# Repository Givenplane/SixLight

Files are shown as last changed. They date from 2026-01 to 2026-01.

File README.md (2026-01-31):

# SixLight – Modular Hexagonal LED System with Adjustable Joints

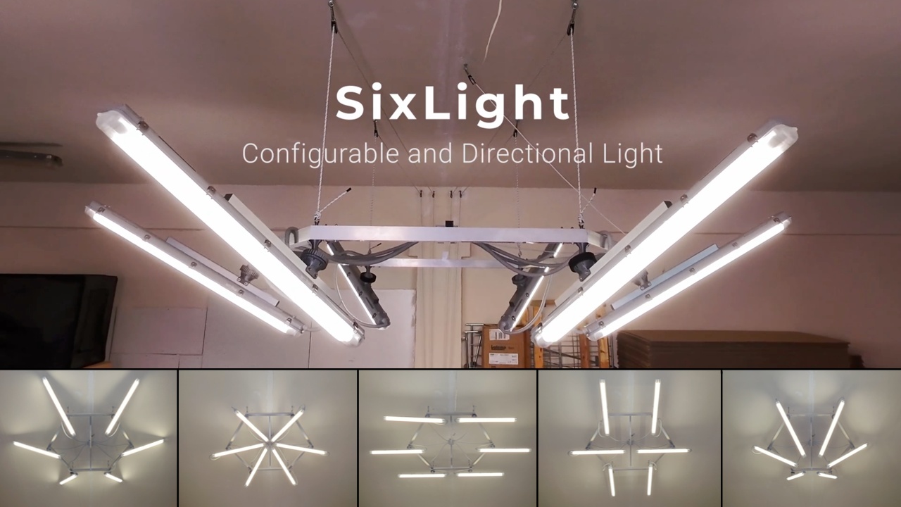
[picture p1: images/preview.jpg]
SixLight Cover


**SixLight** is a modular lighting system designed for creators, makers, and content producers. It combines industrial reliability with DIY flexibility, allowing you to build a durable, adjustable LED light for your studio, workshop, or filming setup.

🎥 **Watch the full video on YouTube:**  
[▶️ SixLight Video](https://www.youtube.com/watch?v=seigdt7EmHs)

---

## 🧱 Structure & Design

SixLight is built around a hexagonal frame made of 50x50 mm aluminum tubes, each 2 mm thick. The industrial LED housings are attached to the frame using custom-designed spherical joints, which allow for a wide range of positioning. Aluminum tubes were chosen to keep the cost low, but using carbon fiber tubes would significantly reduce the weight and improve maneuverability.

Each joint can be tightened to lock the light in a desired direction, offering a semi-rigid structure that remains flexible during setup but stable during use.

---

## 🔩 What's Inside

- 3D-printable STL files for the spherical joints and mounting elements
- STEP files for modification
- [ A short guide](docs/assembly_guide.md) and images of the final assembly

---

## 🚀 Potential Improvements

Here are some possible upgrades and features that could enhance future versions of SixLight:

- **Remote control of individual lamps** for power or on/off switching
- **Brightness adjustment** through dimmable drivers or smart controllers
- **Replacement of the spherical joints** with motorized articulation systems to remotely adjust lamp orientation
- **Motorized ceiling rigging** to raise or lower the four suspension points for positioning and maintenance

---

## 📜 License

This project is licensed under **Creative Commons BY-NC-SA 4.0**.  
You may use, modify, and share this project for **non-commercial** purposes only.

🔒 **Commercial use is not allowed without a separate agreement.**  
If you're a company or manufacturer interested in using or producing this system, please contact us.

---

## ⚠️ Disclaimer

This project is provided **"as is"** without any warranty of any kind, either express or implied.

By using, building, or modifying this project, you agree that:

- You do so **at your own risk**.
- The author(s) are **not responsible for any damage**, injury, or loss that may result from the use or misuse of this design.
- This project involves **electrical components** and **structural parts** that, if improperly built or installed, may cause **fire, electric shock, injury, or property damage**.
- It is **your responsibility** to verify the safety, compliance, and suitability of the design for your specific application.

Always follow local safety regulations and consult a qualified professional when working with electricity or mechanical structures.

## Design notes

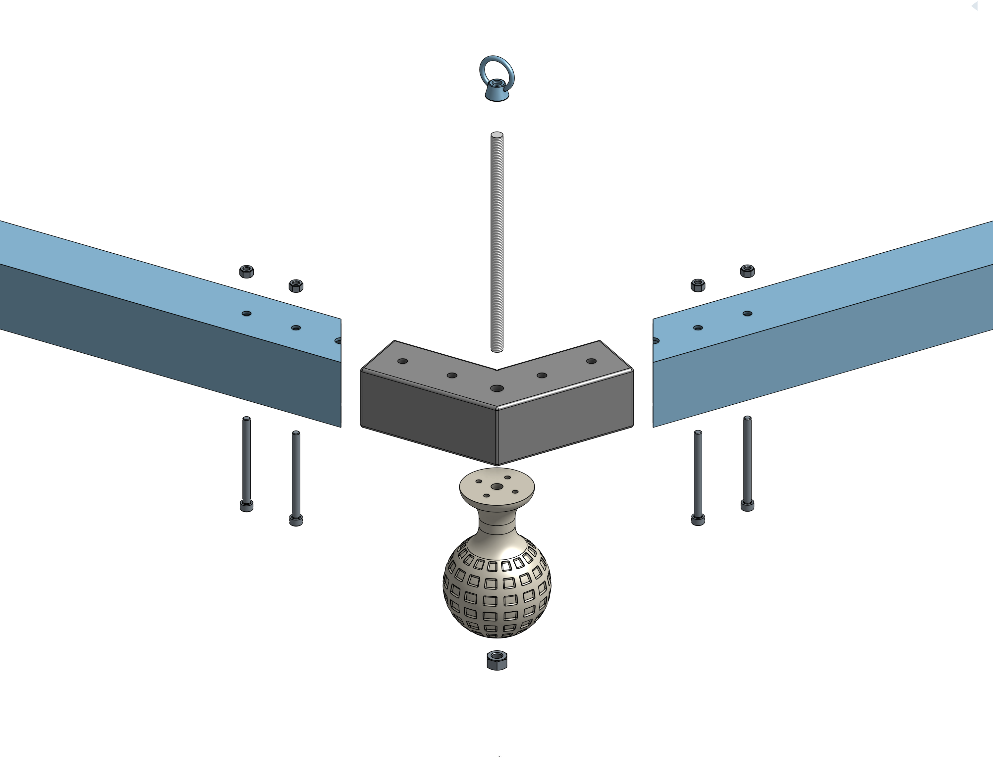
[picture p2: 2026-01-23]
images/hexagon-corner.png

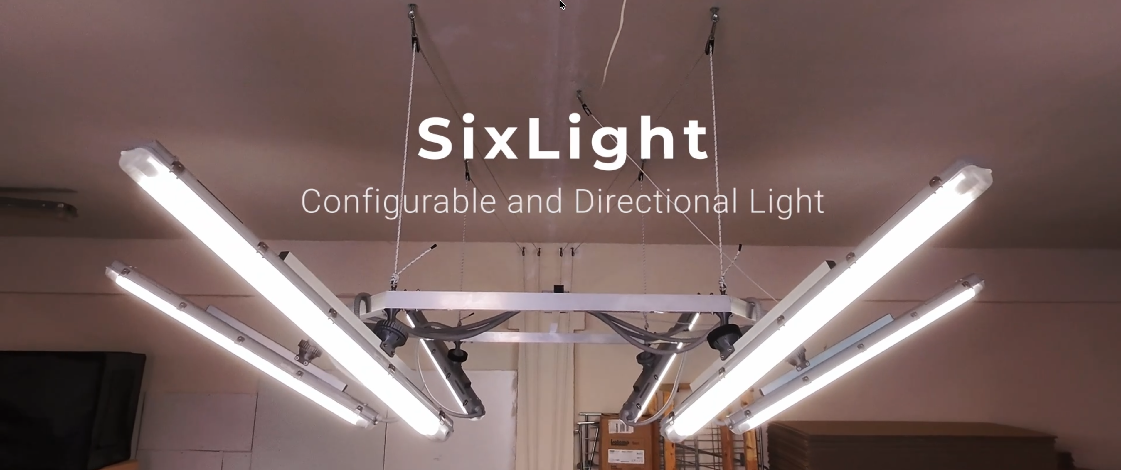
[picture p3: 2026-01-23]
images/cover.png

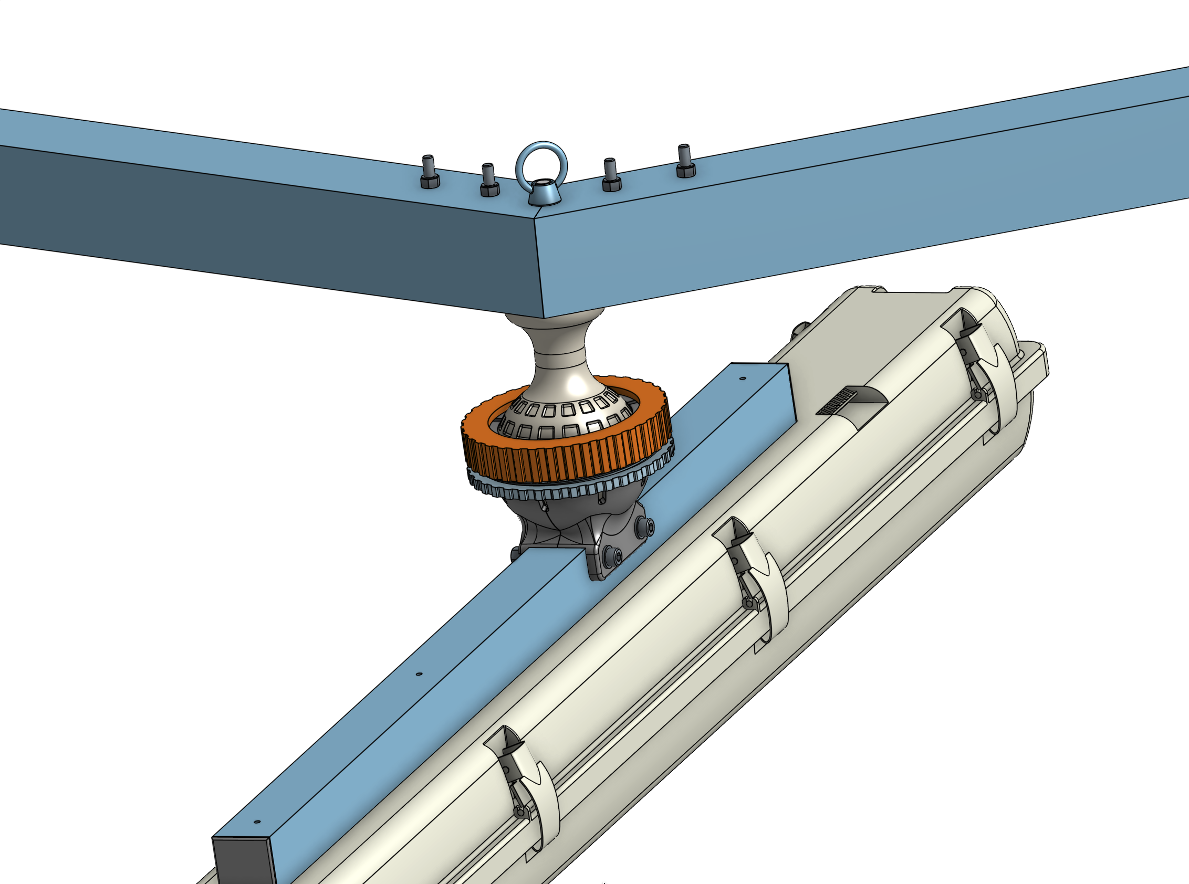
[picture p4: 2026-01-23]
images/ball-joint-tightened.png

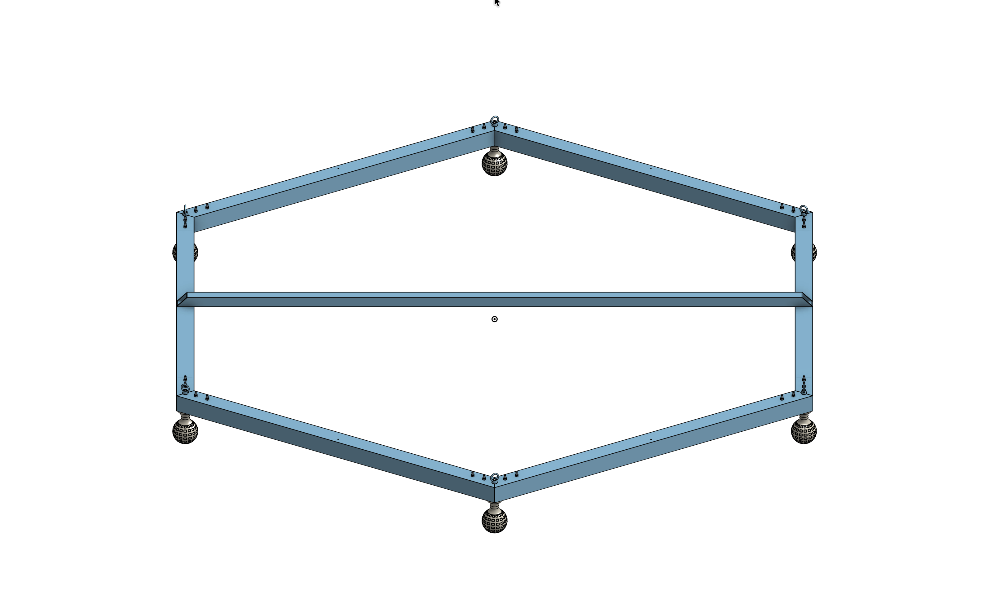
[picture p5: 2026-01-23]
images/hexagon-frame.png

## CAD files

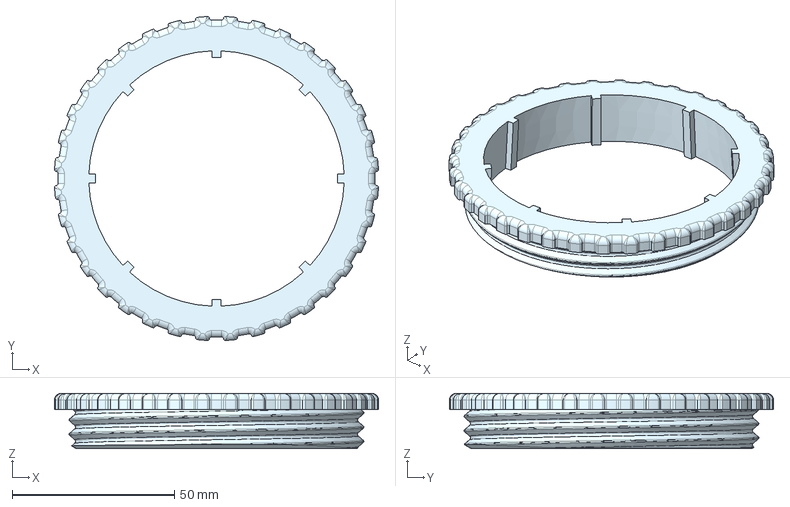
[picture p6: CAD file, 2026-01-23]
3d_models/015-Ball-joint_Male-threaded-ring.step
99.8 x 99.8 x 17.0 mm

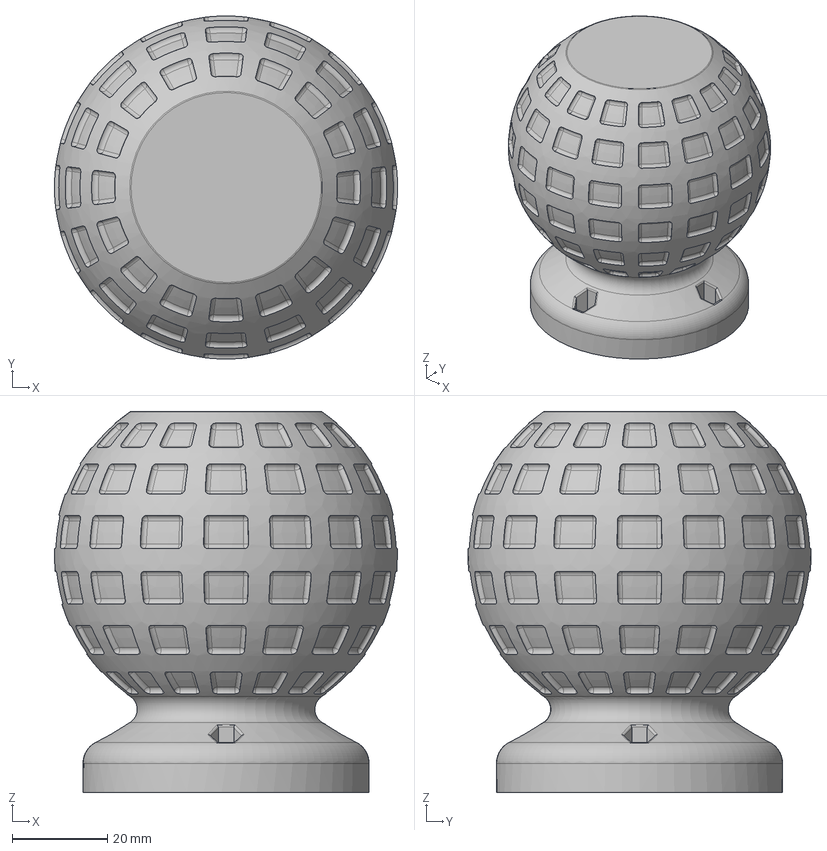
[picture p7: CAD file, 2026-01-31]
3d_models/flat_base_ball_joint/Ball-joint - Sphere.step
71.9 x 71.9 x 79.9 mm

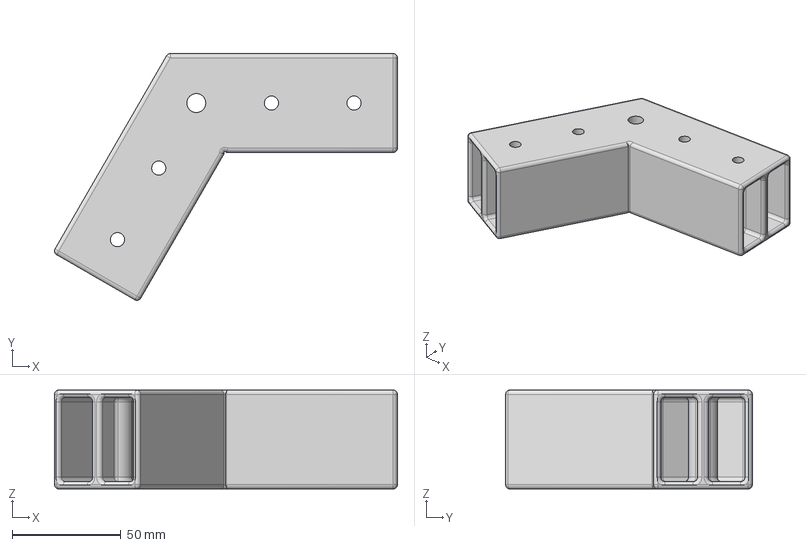
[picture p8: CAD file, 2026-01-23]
3d_models/002-Exagon-structure_Frame-joint.step
157.8 x 113.6 x 45.5 mm

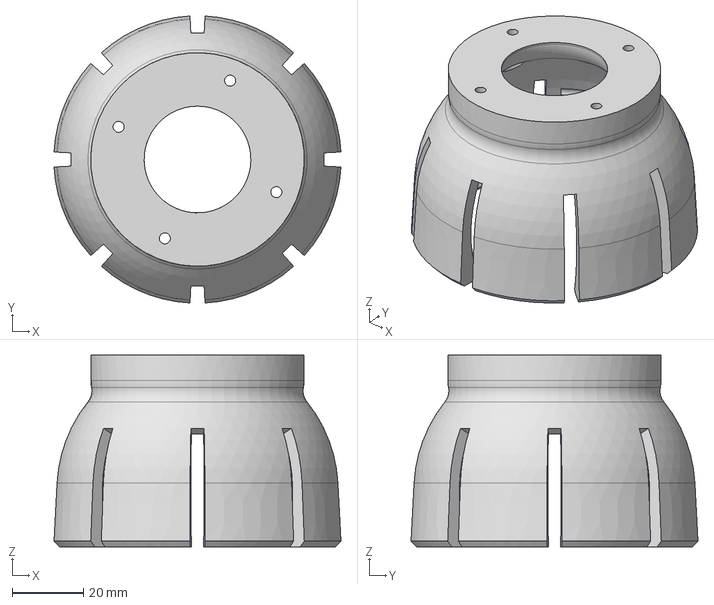
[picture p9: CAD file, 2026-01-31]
3d_models/flat_base_ball_joint/Ball-joint - Fixing.step
80.7 x 80.7 x 53.9 mm

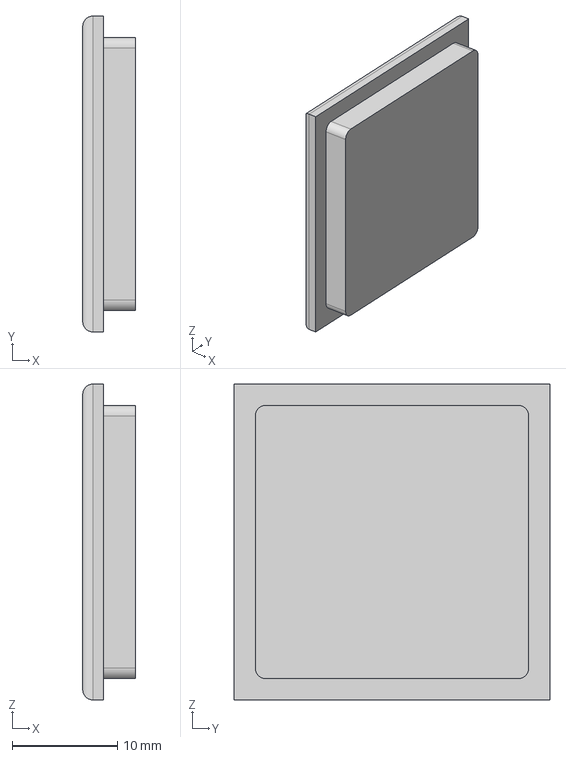
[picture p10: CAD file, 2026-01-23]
3d_models/010-LED-housing_30x30-cap.step
5.00 x 30.0 x 30.0 mm

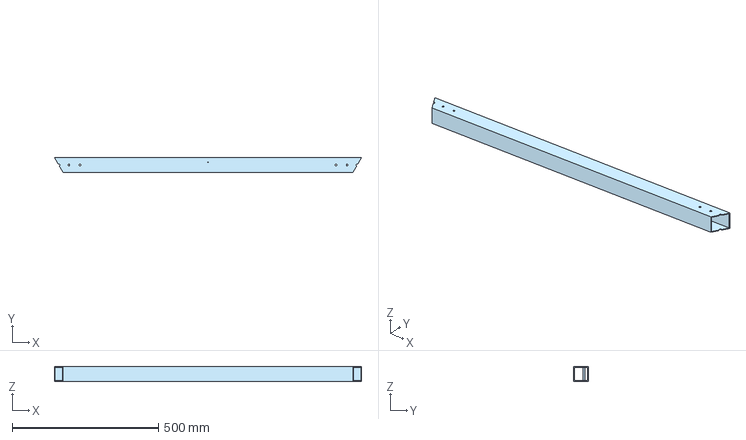
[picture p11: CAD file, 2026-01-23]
3d_models/001-Exagon-structure_Side.step
1050.0 x 50.0 x 50.0 mm

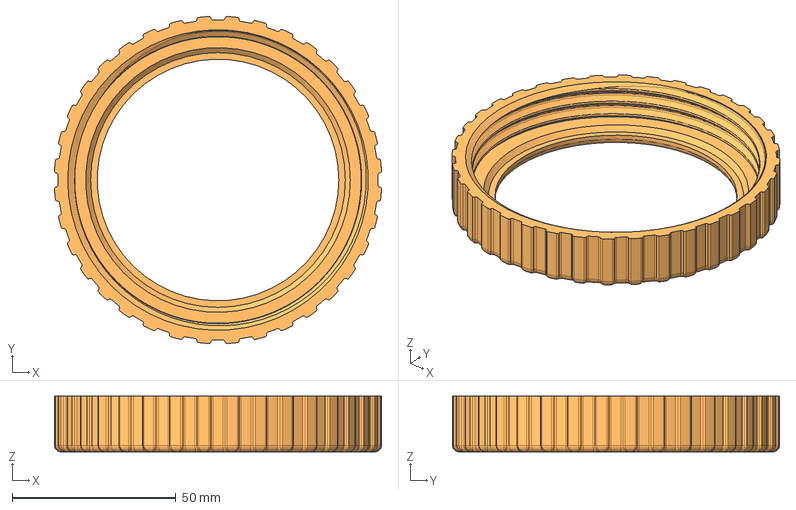
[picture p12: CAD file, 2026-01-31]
3d_models/flat_base_ball_joint/Ball-joint - Female-threaded-ring.step
99.8 x 99.8 x 17.0 mm

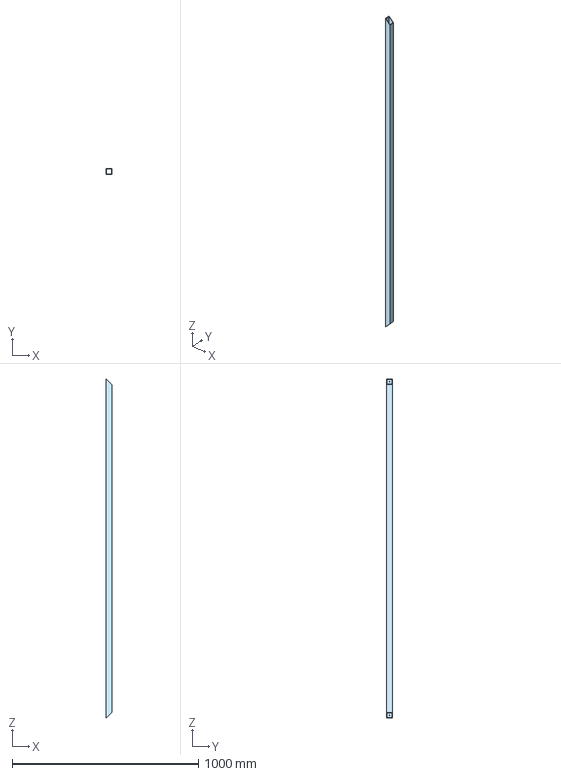
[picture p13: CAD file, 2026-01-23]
3d_models/019-Exagon-structure_Support-bar.step
30.0 x 30.0 x 1818.0 mm

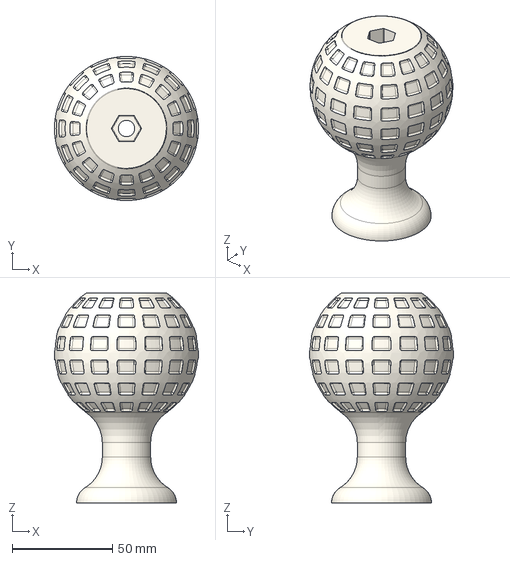
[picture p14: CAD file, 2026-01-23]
3d_models/003-Ball-joint _Sphere.step
72.0 x 72.0 x 104.9 mm

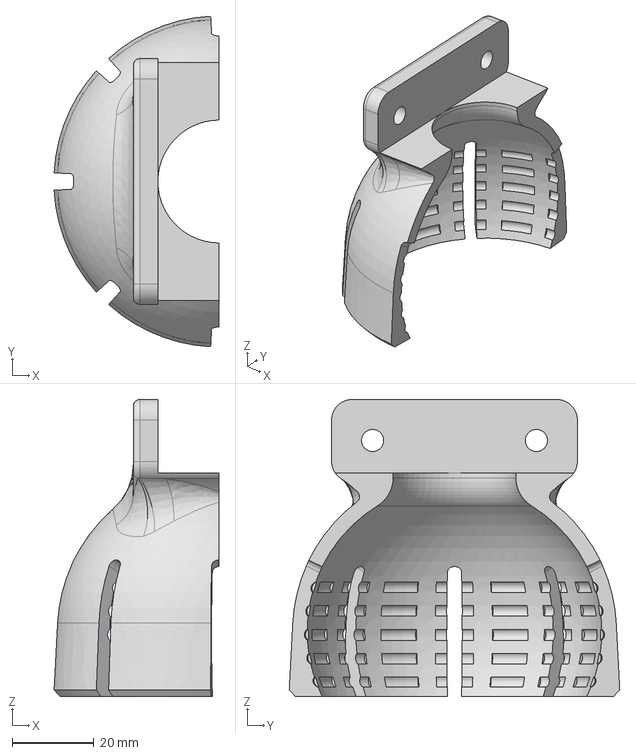
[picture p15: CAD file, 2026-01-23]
3d_models/013-Ball-joint_Fixing.step
40.2 x 80.7 x 72.5 mm

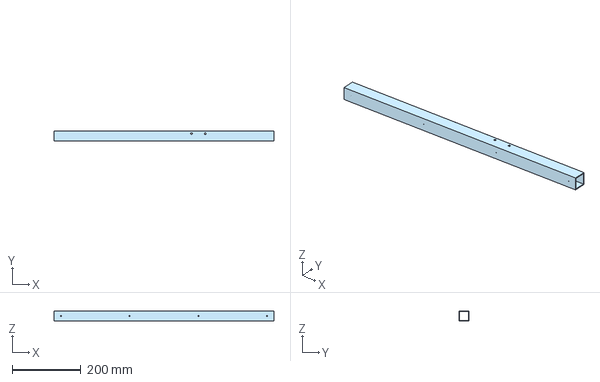
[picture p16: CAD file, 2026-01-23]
3d_models/012-LED-housing_Support.step
640.0 x 30.0 x 30.0 mm

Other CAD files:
3d_models/flat_base_ball_joint/Ball-joint - Male-threaded-ring.step
3d_models/014-Ball-joint_Female-threaded-ring.step
3d_models/flat_base_ball_joint/stl/Ball-joint - Fixing.stl
3d_models/stl/002-Exagon-structure_Frame-joint.stl
3d_models/stl/010-LED-housing_30x30-cap.stl
3d_models/stl/013-Ball-joint_Fixing.stl

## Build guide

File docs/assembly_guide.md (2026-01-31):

# SixLight – Assembly Guide

> This guide covers the assembly of the **SixLight** lamp structure only.  
> This is a short illustrated guide to the **SixLight** lamp structure only.
> Electrical wiring and the ceiling pulley system are not described here but referenced in the final images.

---

## 📦 Part List

| Part number | Quantity | Description |
|---|---|---|
| 001 | 6 | 50x50x1000mm Alluminium profile 2mm thickness |
| 002 | 6 | 3d printed frame joint |
| 003 | 6 | 3d printed sphere |
| 004 | 6 | M8 x 165mm threaded bar |
| 005 | 24 | Hex socket head cap screw M5x0.80 x 65 Stainless Steel |
| 006 | 6 | Self-locking hex nut M8 Stainless Steel |
| 007 | 24 | Hex nut M5 Stainless Steel |
| 008 | 6 | M8 eyebolt |
| *009* | *6* | *Assembly of LED fixtures (cad reference)* |
| 010 | 12 | 3d printed Caps |
| 011 | 6 | Industrial 120cm LED batten housing |
| 012 | 6 | 30x30x640mm Alluminium profile 2mm thickness |
| 013 | 12 | Symmetrical half ball socket |
| 014 | 6 | Female threaded fixing ring |
| 015 | 6 | Male threaded fixing ring |
| 016 | 24 | M5 Stainless Steel washer |
| 017 | 12 | Hex nut M5 Stainless Steel |
| 018 | 12 | Hex socket head cap screw M5 x 50 Stainless Steel |
| 019 | 1 | 30x30x1818mm Alluminium profile 2mm thickness |
| 020 | 24 | Aluminium rivet Ø 3 mm × 10 mm |
| 021 | 2 | Aluminium rivet Ø 5 mm × 10 mm |

---

## 🖨️ 3D Printing Recommendations

All parts were printed using a Bambu Lab X1 Carbon with a 0.6 mm nozzle and basic PLA without any supports.

All components, except for the spherical joint, are printed with **100% infill** for maximum strength.

The sphere is printed with:
- **5 perimeters**
- **6 bottom layers**
- **6 top layers**
- **30% infill**

Since the joint relies on precise fit, it is recommended to **print one piece first** and test the assembly.  
If the fit is too tight or too loose, adjust the slicer's **external dimension parameters** slightly until the desired tolerance is achieved.

!IMPORTANT - To ensure smooth threading and avoid jamming on the layer ridges of the printed part, components 013 (spherical jaw halves) and 015 (male threaded fixing ring) should be sanded with fine-grit sandpaper.

---

## 🧱 Frame Overview

The SixLight frame is composed of six 50x50 mm aluminum tubes arranged in a hexagon.  
At each corner, a 3D printed spherical housing is mounted.

Using carbon fiber tubes instead of aluminum can reduce the total frame weight by over 3 kg, while maintaining similar dimensions.

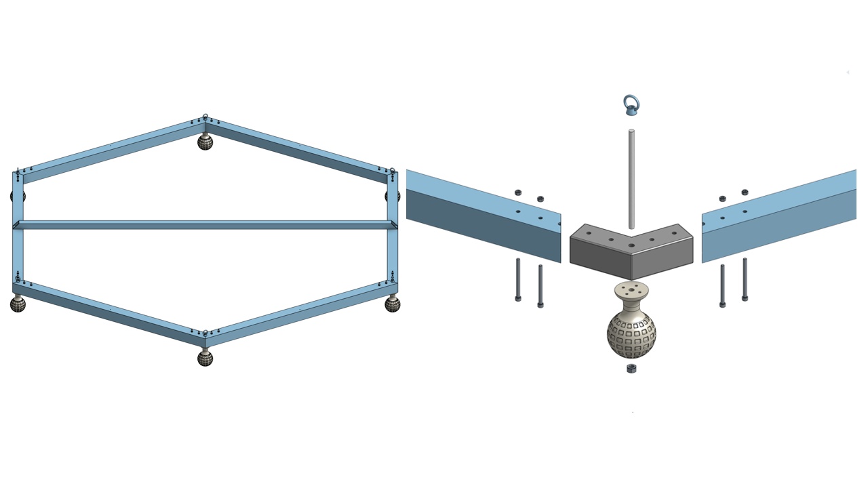
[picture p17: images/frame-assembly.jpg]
SixLight frame assembly


### Parts shown in the picture:
- **001** – 50x50x1000mm Aluminium profile 2mm thickness  
- **002** – 3d printed frame joint  
- **003** – 3d printed sphere  
- **004** – M8 x 165mm threaded bar  
- **005** – Hex socket head cap screw M5x0.80 x 65 Stainless Steel  
- **006** – Self-locking hex nut M8 Stainless Steel  
- **007** – Hex nut M5 Stainless Steel  
- **008** – M8 eyebolt
- **019** - 30x30x1818mm Alluminium profile 2mm thickness

> Apply threadlocker to the M8 eyebolt (part 008) and the M8 self-locking nut (part 006) during assembly to ensure long-term stability.

---

## 💡 LED Fixture Mounting

Each LED batten is mounted on a reinforced aluminum tube (30x30 mm), riveted for strength.  
At each end of the reinforcement bar, two spherical mount halves are fixed to form a housing for the ball joint.

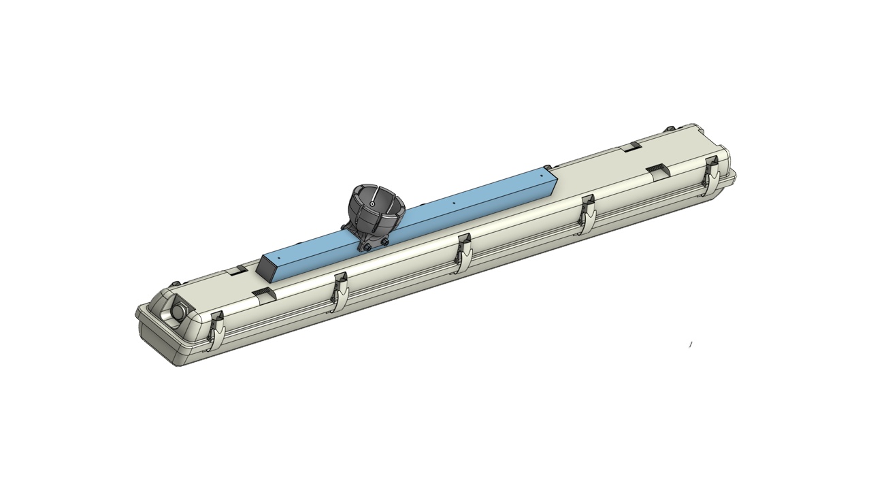
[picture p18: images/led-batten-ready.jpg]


### Parts used in the picture:
- **010** – 3d printed Caps  
- **011** – Industrial 120cm LED batten housing  
- **012** – 30x30x640mm Aluminium profile 2mm thickness  
- **013** – Symmetrical half ball socket  
- **016** – M5 Stainless Steel washer  
- **017** – Hex nut M5 Stainless Steel  
- **018** – Hex socket head cap screw M5 x 50 Stainless Steel  
- **020** – Aluminium rivet Ø 3 mm × 10 mm

---

## 🔧 Spherical Clamp Assembly

Each sphere fits into a set of two spherical jaws that cradle it securely.  
These are held together with a threaded clamping ring.

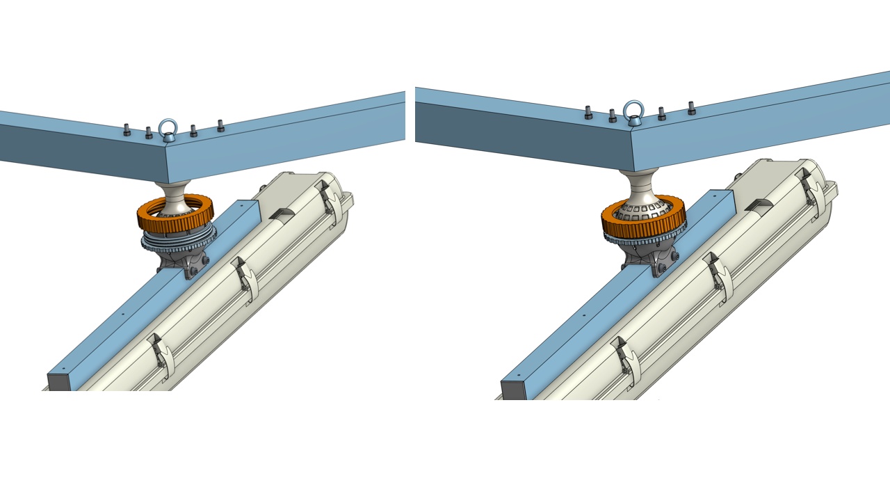
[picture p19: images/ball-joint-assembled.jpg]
SixLight ball joint


### Parts shown in the picture:
- **014** – Female threaded fixing ring
- **015** – Male threaded fixing ring

Once tightened, the lamp remains in the selected position.  
The joint allows for a full 360° rotation and ±30° tilt.

---

## 🖼️ Final Assembly & Installation Example

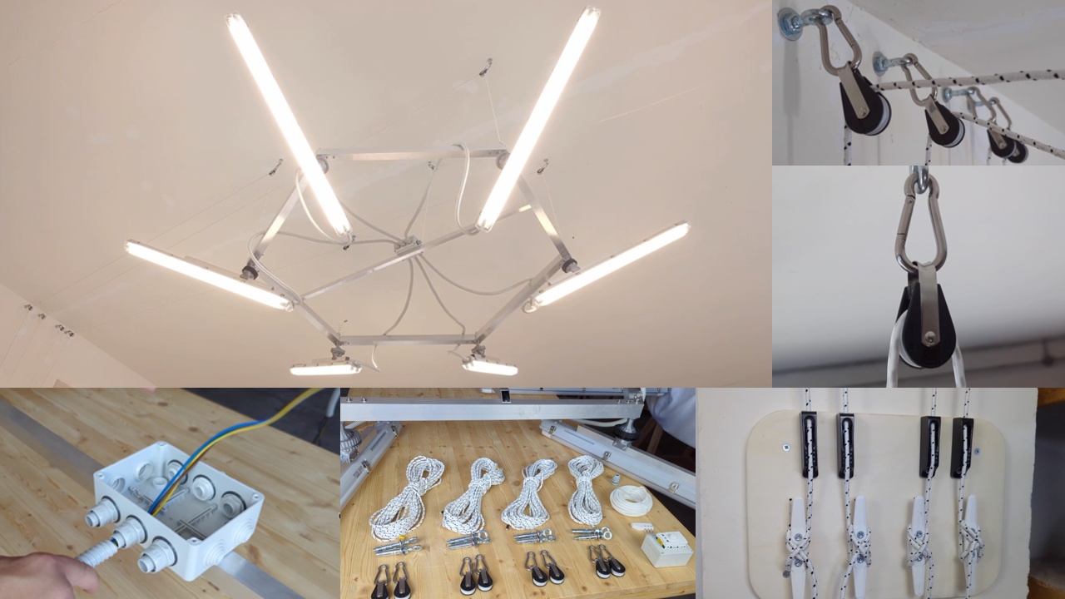
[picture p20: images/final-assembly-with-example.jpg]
SixLight final assembly


This version was fixed to the ceiling using a commercial pulley and cable system.  
The electrical connection is made via standard 220V AC cabling *(see local regulations)*.

---

## ⚠️ Disclaimer

This guide is provided **as is**, without warranty.  
Always ensure proper mechanical and electrical safety during construction and use.

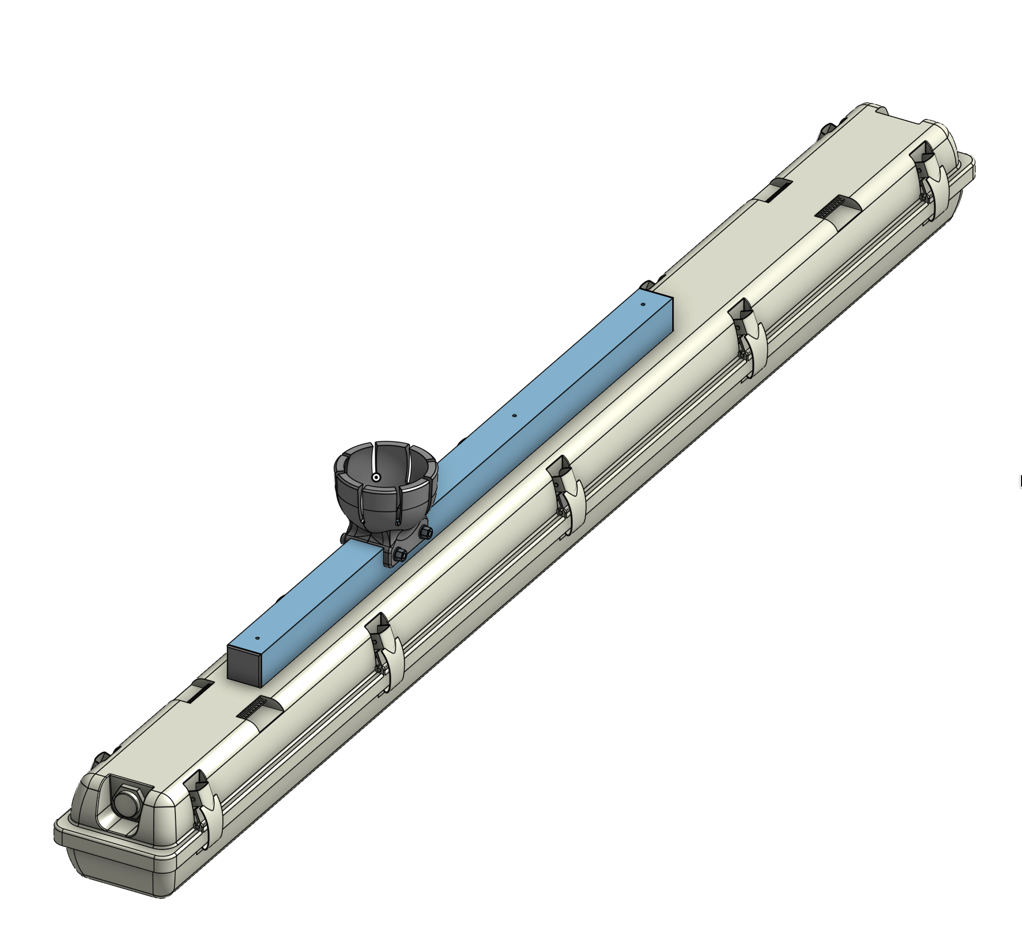
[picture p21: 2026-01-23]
images/LED-batten-assembly.png

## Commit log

2026-01-23 SixLight assembly guide and files
    [001-Exagon-structure_Side.step, 002-Exagon-structure_Frame-joint.step, 002-Exagon-structure_Frame-joint.stl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]
2026-01-31 Update assembly guide with images, part list formatting and YouTube link
    [Ball-joint - Female-threaded-ring.step, Ball-joint - Fixing.step, Ball-joint - Fixing.stl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]
